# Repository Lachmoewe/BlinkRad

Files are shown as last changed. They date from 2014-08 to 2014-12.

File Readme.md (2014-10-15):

# BlinkRad

Using old or broken bicycle rims as an ilumination project.

36 boards, 36 rgb-LEDs, 36 attiny13, 108 FETs, 108 resistors 
(at least if youve got 36 spoke rims).
1 controller of your choice.

## Current Status

Got the current version (as of this commit) of boards at home.
Already got one working with 24bit RGB PWM. Now Im trying
to build a useful and robust data protocol. I was thinking
about sending packages with 4bit per color, a used bit and a 
sync bit, adding up to 14bit packages.

## Further plans
- network control with teensy3.1
- develop a protocol to send to attinys
- maybe 433MHz control
- you name it!

## Getting the code to work
You will need the following packages:
```
sudo apt-get install avr-libc binutils-avr gcc-avr avrdude libusb-dev
```

## Pretty Pictures
<a href="media/pictures/all_small.JPG">
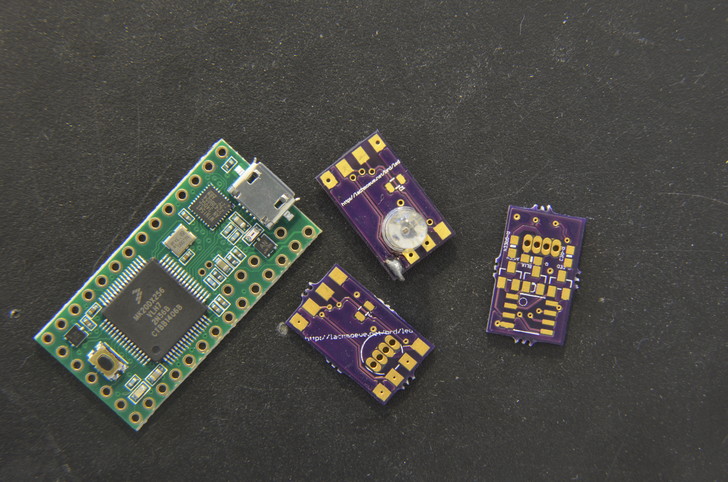
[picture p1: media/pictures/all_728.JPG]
A bunch of small boards

</a>
<a href="media/pictures/led_small.JPG">
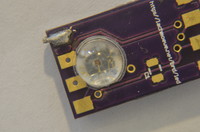
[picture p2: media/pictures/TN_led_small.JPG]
Magnified LED
    
</a>
<a href="media/pictures/grid2_small.JPG">
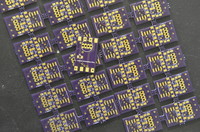
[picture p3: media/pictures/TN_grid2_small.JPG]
Boards from fab
    
</a>
<a href="media/pictures/ledboard_single_small.JPG">
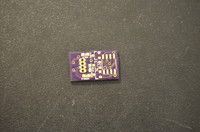
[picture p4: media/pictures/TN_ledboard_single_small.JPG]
One bare ledboard
    
</a>

## Notes
If you want to edit the board, go with either Cadsoft Eagle or
edit the .brd files manually, its only xml.

Thanks to apmorton for creating the teensy template:
https://github.com/apmorton/teensy-template

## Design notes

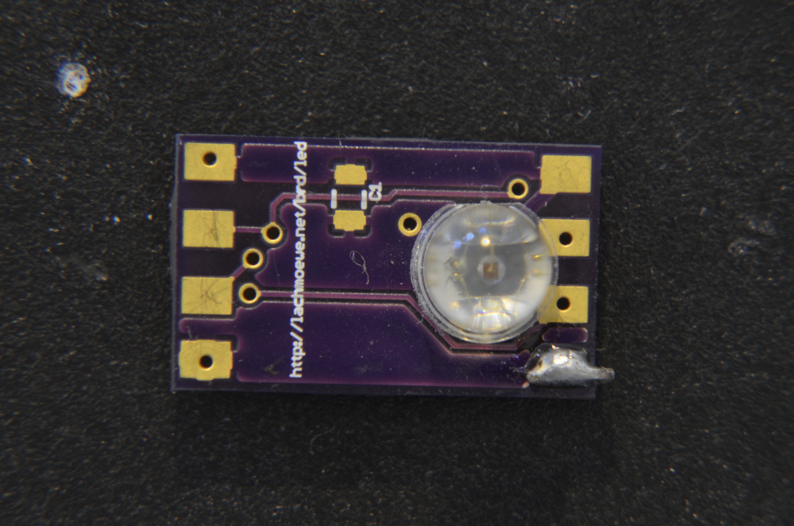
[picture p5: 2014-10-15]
media/pictures/ledboard_populated_small.JPG

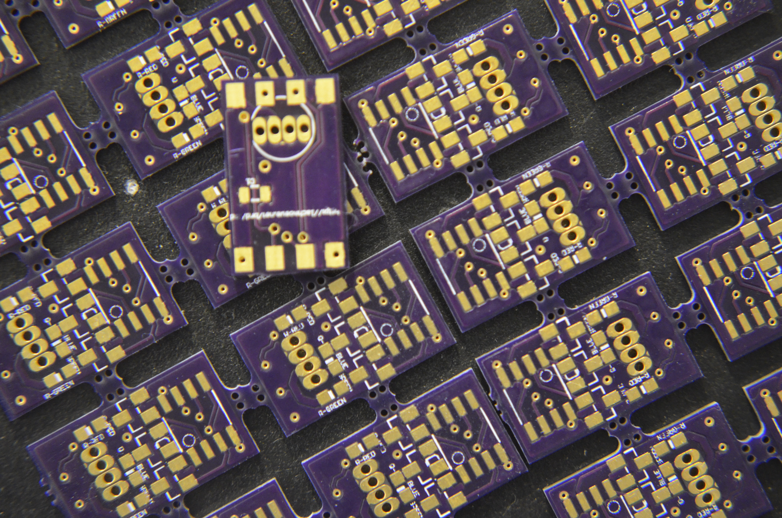
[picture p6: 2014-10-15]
media/pictures/grid1_small.JPG

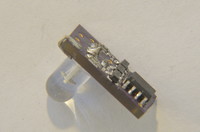
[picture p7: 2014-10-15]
media/pictures/TN_ledboard_populated_side_small.JPG

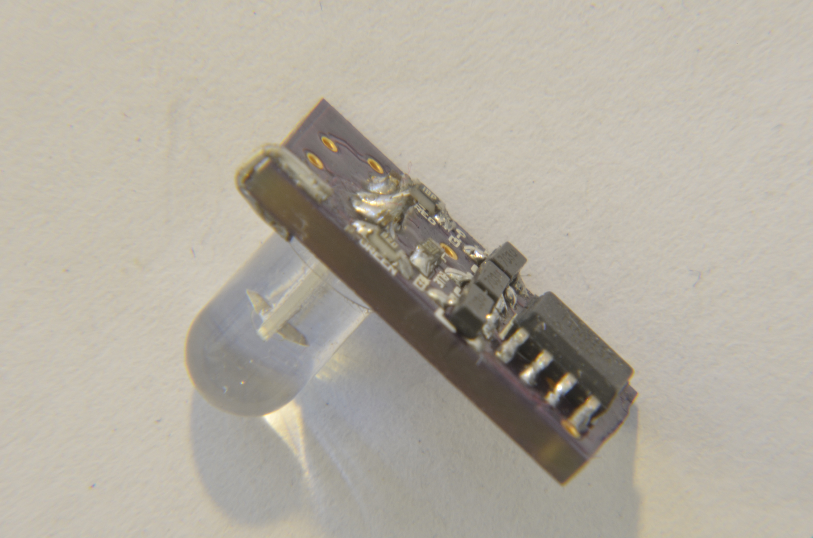
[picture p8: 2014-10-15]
media/pictures/ledboard_populated_side_small.JPG

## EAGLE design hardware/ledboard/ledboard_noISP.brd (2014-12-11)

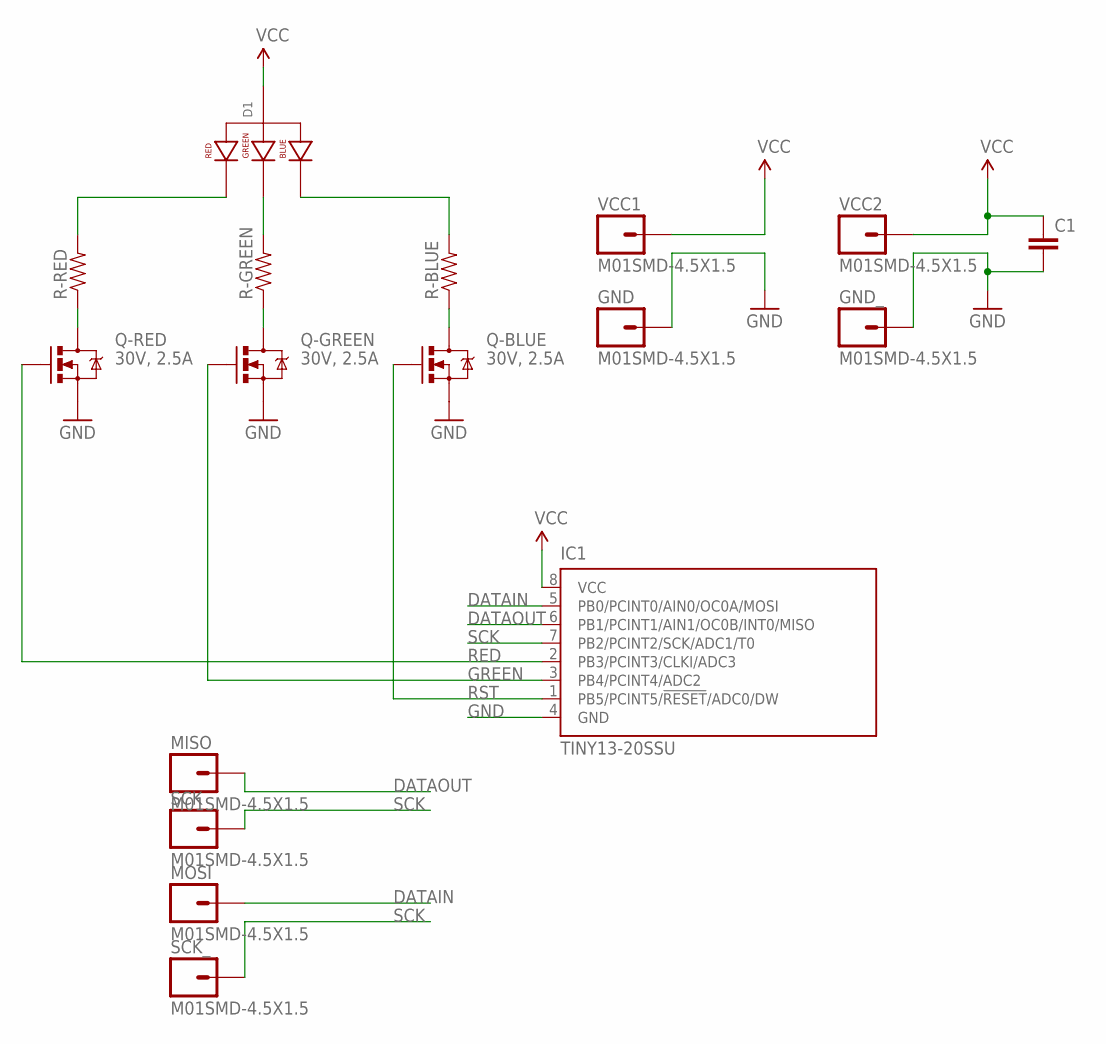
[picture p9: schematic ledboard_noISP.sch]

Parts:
C1: CAP0805; 0805
D1: LED-RGB-CA-THRUCLEAR; LED-RGB-THRU
GND: M01SMD-4.5X1.5; PAD-1.5X4.5
GND_: M01SMD-4.5X1.5; PAD-1.5X4.5
IC1: TINY13-20SSU; 8S1
MISO: M01SMD-4.5X1.5; PAD-1.5X4.5
MOSI: M01SMD-4.5X1.5; PAD-1.5X4.5
Q-BLUE: 30V, 2.5A; SOT23
Q-GREEN: 30V, 2.5A; SOT23
Q-RED: 30V, 2.5A; SOT23
R-BLUE: RESISTOR0603; 0603-RES
R-GREEN: RESISTOR0603; 0603-RES
R-RED: RESISTOR0603; 0603-RES
SCK: M01SMD-4.5X1.5; PAD-1.5X4.5
SCK_: M01SMD-4.5X1.5; PAD-1.5X4.5
VCC1, VCC2: M01SMD-4.5X1.5; PAD-1.5X4.5

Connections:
DATAIN: IC1.5 (PB0/PCINT0/AIN0/OC0A/MOSI), MOSI.P$1
DATAOUT: IC1.6 (PB1/PCINT1/AIN1/OC0B/INT0/MISO), MISO.P$1
GND: C1.2, GND.P$1, GND_.P$1, IC1.4 (GND), Q-BLUE.2 (S), Q-GREEN.2 (S), Q-RED.2 (S)
GREEN: IC1.3 (PB4/PCINT4/ADC2), Q-GREEN.1 (G)
unnamed: D1.1 (RED_CATHODE), R-RED.2
unnamed: Q-RED.3 (D), R-RED.1
unnamed: D1.4 (BLUE_CATHODE), R-BLUE.2
unnamed: D1.3 (GREEN_CATHODE), R-GREEN.2
unnamed: Q-GREEN.3 (D), R-GREEN.1
unnamed: Q-BLUE.3 (D), R-BLUE.1
RED: IC1.2 (PB3/PCINT3/CLKI/ADC3), Q-RED.1 (G)
RST: IC1.1 (PB5/PCINT5/!RESET!/ADC0/DW), Q-BLUE.1 (G)
SCK: IC1.7 (PB2/PCINT2/SCK/ADC1/T0), SCK.P$1, SCK_.P$1
VCC: C1.1, D1.2 (ANODE), IC1.8 (VCC), VCC1.P$1, VCC2.P$1

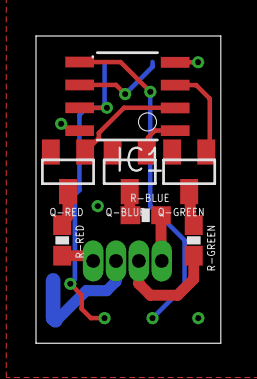
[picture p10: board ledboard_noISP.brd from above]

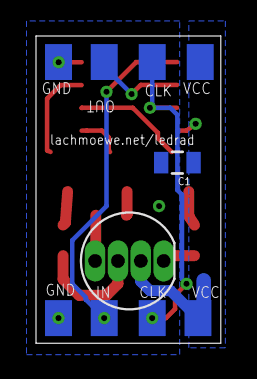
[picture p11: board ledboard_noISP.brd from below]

Board: 2 copper layers, 10.3 x 17.1 mm, 17 parts (10 on the bottom side), 14 nets.

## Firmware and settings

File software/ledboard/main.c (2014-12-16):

#define F_CPU 8000000UL
#include <stdlib.h>
#include <avr/io.h>
#include <util/delay.h>
#include <stdint.h>

#define SCK     PB2
#define DATAIN  PB0
#define DATAOUT PB1

uint8_t r,g,b;

const uint8_t lookup[16] = {
    0, 3, 7, 12, 19, 26, 35, 45, 58, 73, 91, 113, 140, 171, 209, 254
};

int PWM(void) {
    static uint8_t pwm_count = 0;
    if      (pwm_count == 0) { PORTB |= (1<<PB3)|(1<<PB4)|(1<<PB5); }
    else if (pwm_count == r) { PORTB &= ~(1<<PB3); }
    else if (pwm_count == g) { PORTB &= ~(1<<PB4); }
    else if (pwm_count == b) { PORTB &= ~(1<<PB5); }
    
    pwm_count++;
}

void setColor(uint16_t cdata) {
    r = lookup[(cdata & 0x0F00)>>8];
    g = lookup[(cdata & 0x00F0)>>4];
    b = lookup[cdata & 0x000F];
}

int main(void) {

    DDRB = 0b00111010;
    // Set up Port B data to be all low
    PORTB = 0;  
    
    r = 0;
    g = 255;
    b = 255;

    uint8_t bit_count = 0;
    uint8_t sck_oldstate = 0;
    uint8_t gotdata = 0;
    uint8_t databit = 0;
    uint16_t data = 0;

    const uint16_t sync_sequence = 0x3FFF;    // 14 bit set to 1
    const uint16_t pattern       = 0x3FFF;          // 14 bit set to 1
    const uint16_t syncbit       = 0x2000;
    const uint16_t usedbit       = 0x1000;

    while (1) {
        // Toggle Port B pin 4 output state
        if ((PORTB && (1<<SCK)) && !sck_oldstate) { // check if sck rised
            sck_oldstate = 1;

            // read datain pin, shift data one left and write databit to lowest pos
            if (PORTB & (1<<DATAIN)) { databit = 1; } else { databit = 0; }
            data = (data<<1);
            data |= databit;

            // set 4 highest bits 0
            data = data & pattern;
            
            if (bit_count == 13) {          // check if we received a full package yet
                if (!(data && usedbit)) {      // check if this package was already used
                    if (!gotdata) {
                        gotdata = 1;
                        setColor( (data & 0x0FFF) ); // send only rgb info
                    }
                }
            }
            bit_count++;

            if (bit_count == 14) {
                bit_count = 0;
            }
            if (data == sync_sequence) {
                // we just found a sync sequence, reset the bit counter
                bit_count = 0;
                gotdata = 0;
            } 

        } else if (!(PORTB & (1<<SCK)) && sck_oldstate){ // check if sck fell
            sck_oldstate = 0;
            
            // write dataout pin
            if (databit == 1) {
                PORTB |= (1<<DATAOUT);
            } else if ( (bit_count == 1) && !gotdata && !databit ) {
                // this sets the usedbit for the first unusedpackage in the datastream
                PORTB |= (1<<DATAOUT);
            } else {
                PORTB &= ~(1<<DATAOUT);
            }
        }
        PWM();
        _delay_us(1);
    }

    return 0;
}

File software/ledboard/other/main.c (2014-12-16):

#include <stdio.h>
#include <stdint.h>


const uint8_t lookup[16] = {
    0,3,7,12,19,26,35,45,58,73,91,113,140,171,209,254
};

void setColor(uint16_t cdata, uint8_t *color) {
    *(color)   = lookup[(cdata & 0x0F00)>>8];
    *(color+1) = lookup[(cdata & 0x00F0)>>4];
    *(color+2) = lookup[(cdata & 0x000F)];
}


int main(void) {
    uint8_t color[3];
    uint8_t *cptr;
    cptr = &color[0];
    uint16_t i = 0;
    while (i<=0x0FFF) {
        setColor(i, cptr);
        printf("0x%x: %d %d %d\n", i,color[0],color[1],color[2]);
        i++;
    }
    return 0;
}

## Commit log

2014-08-10 MASSIVE ERROR, USE N FET
    [ledboard_noISP.brd, ledboard_noISP.sch]
2014-10-13 changes in folder hierarchy
    [ledboard.brd, ledboard.sch, ledboard_noISP.brd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]
2014-10-14 fixed error with used_oldstate
    [main.c]
2014-10-14 included teensy toolchain
2014-10-14 not about teensy-template
2014-10-16 led now has all diodes fully on on startup
2014-10-22 named dataports
    [ledboard_noISP.brd, ledboard_noISP.sch]
2014-10-22 added labels
    [ledboard_noISP.brd]
2014-12-08 moving on with teensy code, so far nothing seems to work
2014-12-11 fiddling around, teensy does everything it should, ledboard doesnt
2014-12-11 prettyfied pwm
2014-12-11 fixed board fuckup
    [ledboard_noISP.brd]
2014-12-11 fixed bug with gotdata
    [main.c]

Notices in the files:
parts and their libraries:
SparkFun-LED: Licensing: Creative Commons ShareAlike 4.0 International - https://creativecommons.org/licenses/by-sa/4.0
